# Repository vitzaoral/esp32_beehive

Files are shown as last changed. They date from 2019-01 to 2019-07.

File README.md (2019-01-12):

# esp32_beehive
Beehives online monitoring based on the ESP32, SIM800L and others sensors.

> To build a project, you need to download all the necessary libraries and create the *settings.cpp* file in the *src* folder:
```c++
// Project settings
struct Settings
{
    const char *blynkAuth = "You Blynk Auth";
    const char *version = "1.0.0";
    const char *firmawareUrlBase = "http://your-address.com/";
    const char *firmwareFileName = "bee_hive";
    const char *firmwareVersionFileName = ".version";
};
```

### Currents list:

* [ESP32 WROOM-32](https://www.aliexpress.com/item/ESP32-ESP-32-ESP32S-ESP-32S-CP2102-Wireless-WiFi-Bluetooth-Development-Board-Micro-USB-Dual-Core/32867696371.html)
* TODO

### Schema:
TODO
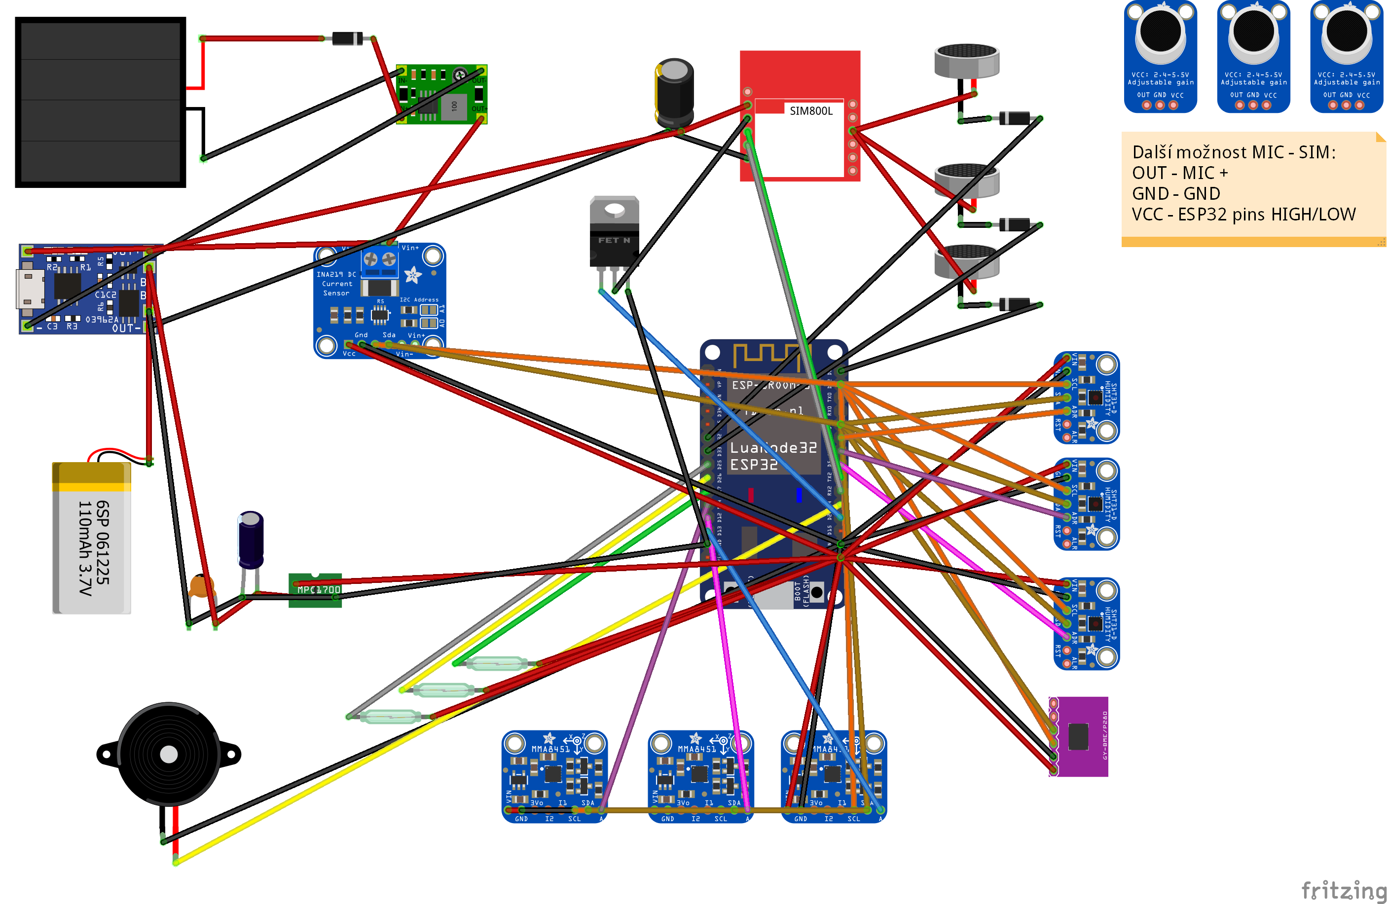
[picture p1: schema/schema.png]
Schema


### Powering:
3v3 regulator - https://randomnerdtutorials.com/esp8266-voltage-regulator-lipo-and-li-ion-batteries/

### GMS antenna interferes with I2C bus communication:
TODO - https://electronics.stackexchange.com/questions/36906/radio-interferes-with-i2c-bus-communication

### PCB circuit:
* TODO

### Blynk:
* TODO

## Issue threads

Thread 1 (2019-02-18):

Solar panel to buck regulator to linear regulator?

romankc, 2019-02-18:
I see that you are wanting to charge a Lithium Ion battery from a solar panel.
In your current design, you will experience some efficiency loss in the DC-DC converter and additional loss in the linear charge controller, about 15% total loss in the very best case scenario and 30% typically.

Why not use a DC-DC step down battery charging IC instead?

vitzaoral, 2019-02-21:
Hello, thanks for your comment.
I am not sure if I correctly understand which part of design is wrong.

Battery charging is done by the [TP4056 charging board](https://www.aliexpress.com/item/Smart-Electronics-5V-Micro-USB-1A-18650-Lithium-Battery-Charging-Board-With-Protection-Charger-Module-for/32500042672.html). According to [this video](https://www.youtube.com/watch?v=dBx-g1dkdDQ) is most efficient. Unfortunately, the maximum input for TP4056 is 6V, then it does not work. Solar panels on direct sun can get up to 7V, so I used this[ DC-DC Step Down](https://www.aliexpress.com/item/Ultra-Small-Size-DC-DC-Step-Down-Power-Supply-Module-3A-Buck-Converter-Adjustable-1-8V/32880983608.html) regulator to convert solar output to 5V. There is some efficiency loss.

Then I need to power ESP32 with 3.3V. Voltage of battery is between 4.2V - 3.0V. I tried several DC-DC step down regulator and finally I used [DD0503MA](https://www.aliexpress.com/item/Ultra-Small-mini-DC-3-7V-4-2V-4-5V-5V-6V-to-3-3V-Step/32654976787.html) 3.3V regulator to power ESP32 with battery.  There is some efficiency loss too.

So there are two regulators - one for solar panel and other one for ESP32. If you have some advice how to design power managing better, I will be grateful.
Thank you.

romankc, 2019-02-21:
For powering the ESP32, consider these: TPS62740, TPS78330, TPS62203.
You can achieve higher efficiency by using an IC which is specifically designed for low levels of current.
At these low current levels, and especially while the device is sleeping, the quiescent current is very important.

I know of that YouTube video. Unfortunately the entire test process that he used is wrong so the results are wrong.

Suppose your solar panel outputs 7V and your battery has a voltage of 3.7V before you begin charging.
We'll suppose that your DC-DC converter has negligible loses.
You feed the TP4056 with 5V and it regulates down to 3.7V.
3.7/5=74%.

You lose at least 26% of your solar panel power!

Even if the battery is almost fully charged, 4.2V/5V, you still lose at least 16% on the TP4056 at an input of 5V.

This is why you need to use a step down converter to go directly from the solar panel to the battery.

What is the current rating of your panel?

vitzaoral, 2019-02-21:
Thank you for your reply, I will consider using the TPSXXXXX converters, I did not know about them.

I am a 90% software developer, so I do not have enough knowledge of how to design a solid circuit (at least it works:) But I understand what you're saying. So you propose to remove TP4056 and use convertor directly to charging battery.

I am using [this solar panels](https://www.aliexpress.com/item/BUHESHUI-6V-1000mA-6W-Mini-Monocrystalline-PET-Solar-Panel-Small-Solar-Cell-Battery-Bicycle-Sharing-Share/32832618716.html) - 6V 1000mA 6W. I am using two of them (parallel connected).

romankc, 2019-02-22:
[This](https://www.aliexpress.com/item/1S-Cell-Li-ion-Lithium-Battery-lipo-battery-Charger-Board-Module-3-7V-4-2V-CN3791/32862470804.html), or any other CN3791 based module, may work well for you. Just make sure that you get the 6V version. The 9V and 12V versions appear to be half the price and you can convert them to 6V by changing one resistor.

Compare it side by side with your design and let me know the results.

Hint: Stick an INA219 before and after the charge controller to measure the efficiency.

romankc, 2019-02-22:
Oh, also try your panels in series (with a 12V CN3791) and see if this gives you better or worse overall power production.

vitzaoral, 2019-05-17:
Hi @romankc .
So finally I use 2x 6V solar panels connected in series with 12V version CN3791 and it works great. I think it works better than 6V version. Thank you.

Closed 2019-05-17.

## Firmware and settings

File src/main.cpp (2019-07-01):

#include <Arduino.h>
#include <InternetConnection.h>
#include <Ticker.h>

// funkcni verze TinyGSM 0.3.6, 0.6.2 delala bordel

// cervenby S09 start 13.2. v 21:30 - 14.2. 23:30 - 26 hodin
// DD0503MA start 15.2. 7:30 - 16.2. 13:45 - 30 hodin
// 403MA start 18.2. 7:30 - 19.2. 11:45 - 28 hodin

// DD0503MA bez senzoru start 20.2. 7:30 - 15:30 - 32 hodin

// TODO: zkusit max. napeti pro TP4056 a na to nastavit regulator za solarem (ale bude to fungovat pro mensi napeti..?)

InternetConnection connection;
MeteoData meteoData;
PowerController powerController;
GyroscopeController gyroscopeController;
MagneticLockController magneticLockController;
SirenController SirenController;

void sendDataToInternet();
void checkIncomingCall();
void checkGyroscopeAlarm();
void checkMagneticLockAlarm();

Ticker timerSendDataToInternet(sendDataToInternet, 288000);  // 4.8 min 300000
Ticker timerCheckIncomingCall(checkIncomingCall, 5125);      // 5 sec
Ticker timerGyroscopeAlarm(checkGyroscopeAlarm, 5321);       // 5 sec
Ticker timerMagneticLockAlarm(checkMagneticLockAlarm, 4321); // 4 sec

// alarm section
void sendDataToBlynkIfAlarm();
Ticker timerSendDataToBlynkIfAlarm(sendDataToBlynkIfAlarm, 20000); // 20 sec

// TODO: sound level measuring
// TODO: mic switchinng

void setup()
{
  Serial.begin(115200);

  connection.initialize();

  timerSendDataToInternet.start();
  timerCheckIncomingCall.start();
  timerGyroscopeAlarm.start();
  timerMagneticLockAlarm.start();
  timerSendDataToBlynkIfAlarm.start();

  meteoData.initializeSensors();

  // set first data for gyroscope and magnetic locks, other in timers..
  gyroscopeController.setData();
  magneticLockController.setData();
  Serial.println("Setup done, send first data");
  sendDataToInternet();
  Serial.println("First data sended, start loop");
}

void loop()
{
  timerSendDataToInternet.update();
  timerCheckIncomingCall.update();
  timerGyroscopeAlarm.update();
  timerMagneticLockAlarm.update();
  timerSendDataToBlynkIfAlarm.update();

  connection.blynkRunIfAlarm();
}

void checkIncomingCall()
{
  connection.checkIncomingCall();
}

void sendDataToInternet()
{
  Serial.println("Start initialize Blynk connection");
  if (connection.initializeConnection())
  {
    Serial.println("Setting sensors data");
    meteoData.setData();
    powerController.setData();
    // gyroscope and magnetic locks data are set in other timer more often, so we have actual data

    Serial.println("Sending data to Blynk");
    connection.setMicrophoneGain();
    connection.sendDataToBlynk(meteoData, powerController, gyroscopeController, magneticLockController);
    connection.checkNewVersionAndUpdate();
    connection.disconnect();
  }
  else
  {
    Serial.println("No internet connection");
  }
}

void checkGyroscopeAlarm()
{
  gyroscopeController.setData();
  if (gyroscopeController.isOk())
  {
    // update blynk data and turn alarm off
    if (connection.isAlarm)
    {
      connection.setGyroscopeControllerDataToBlynkIfAlarm(gyroscopeController);
    }
    connection.isAlarm = false;
  }
  else
  {
    connection.isAlarm = true;
    connection.alarmGyroscopeController(gyroscopeController);
  }
}

void checkMagneticLockAlarm()
{
  magneticLockController.setData();
  if (magneticLockController.isOk())
  {
    // update blynk data and turn alarm off
    if (connection.isAlarm)
    {
      connection.setMagneticLockControllerDataToBlynkIfAlarm(magneticLockController);
    }
    connection.isAlarm = false;
  }
  else
  {
    connection.isAlarm = true;
    connection.alarmMagneticController(magneticLockController);
  }
}

void sendDataToBlynkIfAlarm()
{
  connection.setMagneticLockControllerDataToBlynkIfAlarm(magneticLockController);
  connection.setGyroscopeControllerDataToBlynkIfAlarm(gyroscopeController);
  connection.checkSirenAlarm();
}

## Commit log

2018-12-22 InternetConnection, MeteoData, Power controller
2018-12-23 Multiple SHT3X sensors, first project schema
    [schema.fzz]
2018-12-23 Update schema
    [schema.fzz]
2019-01-10 Send first data after setup is done, sync with Blynk server after reconnected, schema
    [schema.fzz]
2019-01-12 Restart device from Blynk
2019-01-12 Added MMA845X gyroscope sensors support
    [schema.fzz]
2019-01-13 I2C restart, Magnetic locks sensors logic, schema..
    [schema.fzz]
2019-01-14 BME/BMP280 outdoor sensor, meteoDSata refactor
2019-02-05 Updated TinyGSM library, outdoor meteo sensor, alarmController, schemma
    [schema.fzz]
2019-02-09 Gyroscope moduls, magnetic locker, meteo sensors
2019-02-09 Incoming call - 3 microphones changin logic
    [schema.fzz]
2019-02-11 Alarm controller, siren, schema
    [schema.fzz]
2019-02-25 Send push notification to mobile when magnetic locker is open
2019-02-25 Magnetic locks push notifications logic
2019-02-27 Magnetic lockers alarm logic
2019-03-01 Gyroscope alarm logic
2019-03-07 Print to Blynk virtual terminal
2019-03-10 Alarm when gyroscope sensor is not available
2019-03-14 Better modem/GPRS init, Hardware modem reset
    [schema.fzz]
2019-04-04 Change pin + schema
    [schema.fzz]
2019-04-17 Small internet connection changes
    [schema.fzz]
2019-05-21 Delay for temperature/gyroscope sensors. Gain for microphone.
    [schema.fzz]
